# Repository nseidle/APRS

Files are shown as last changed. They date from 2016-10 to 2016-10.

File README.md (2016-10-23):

APRS Entry for 2016 SparkFun AVC
===========================================================

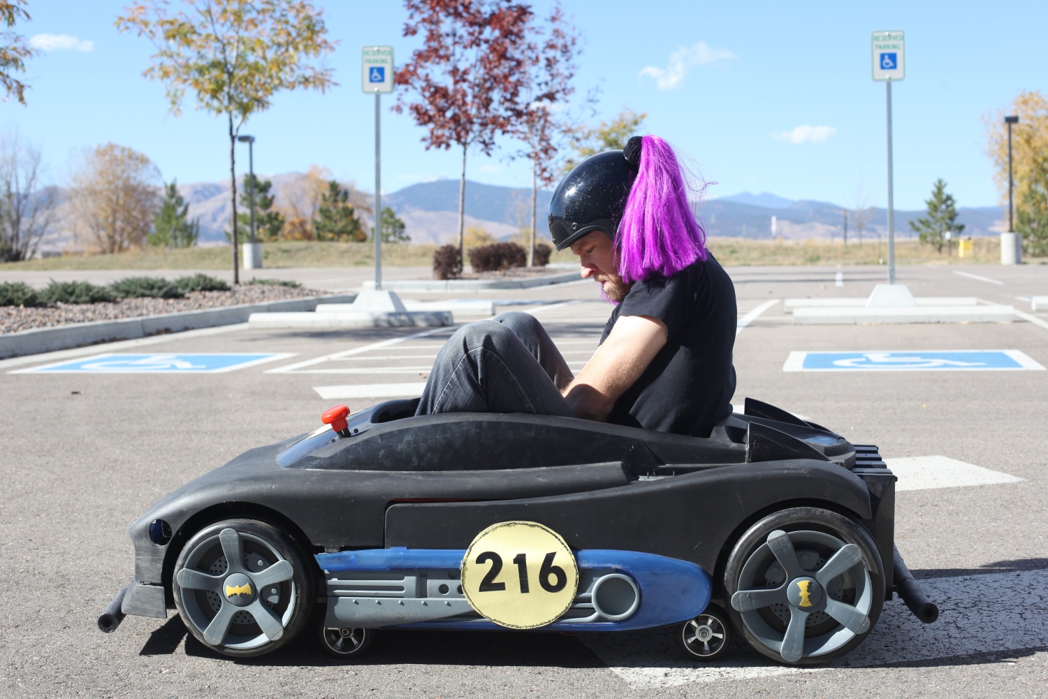
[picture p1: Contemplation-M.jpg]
Nathan in a A+PRS vehicle


This repo contains all the code and PCB layouts used on the A+PRS vehicle Alicia and I entered in the 2016 SparkFun AVC.

Repository Contents
-------------------

The vehicle is broken into sub-systems in order to eat the elephant. Each directory is a sub-system.

Documentation
--------------

There's a tutorial being written.

License Information
-------------------

This is _**open source**_! 

Please use, reuse, and modify these files as you see fit. Please maintain attribution to SparkFun Electronics. Any derivative must be released under the same license.

Distributed as-is; no warranty is given.

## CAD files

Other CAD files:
Old/Models/Chassis.skp

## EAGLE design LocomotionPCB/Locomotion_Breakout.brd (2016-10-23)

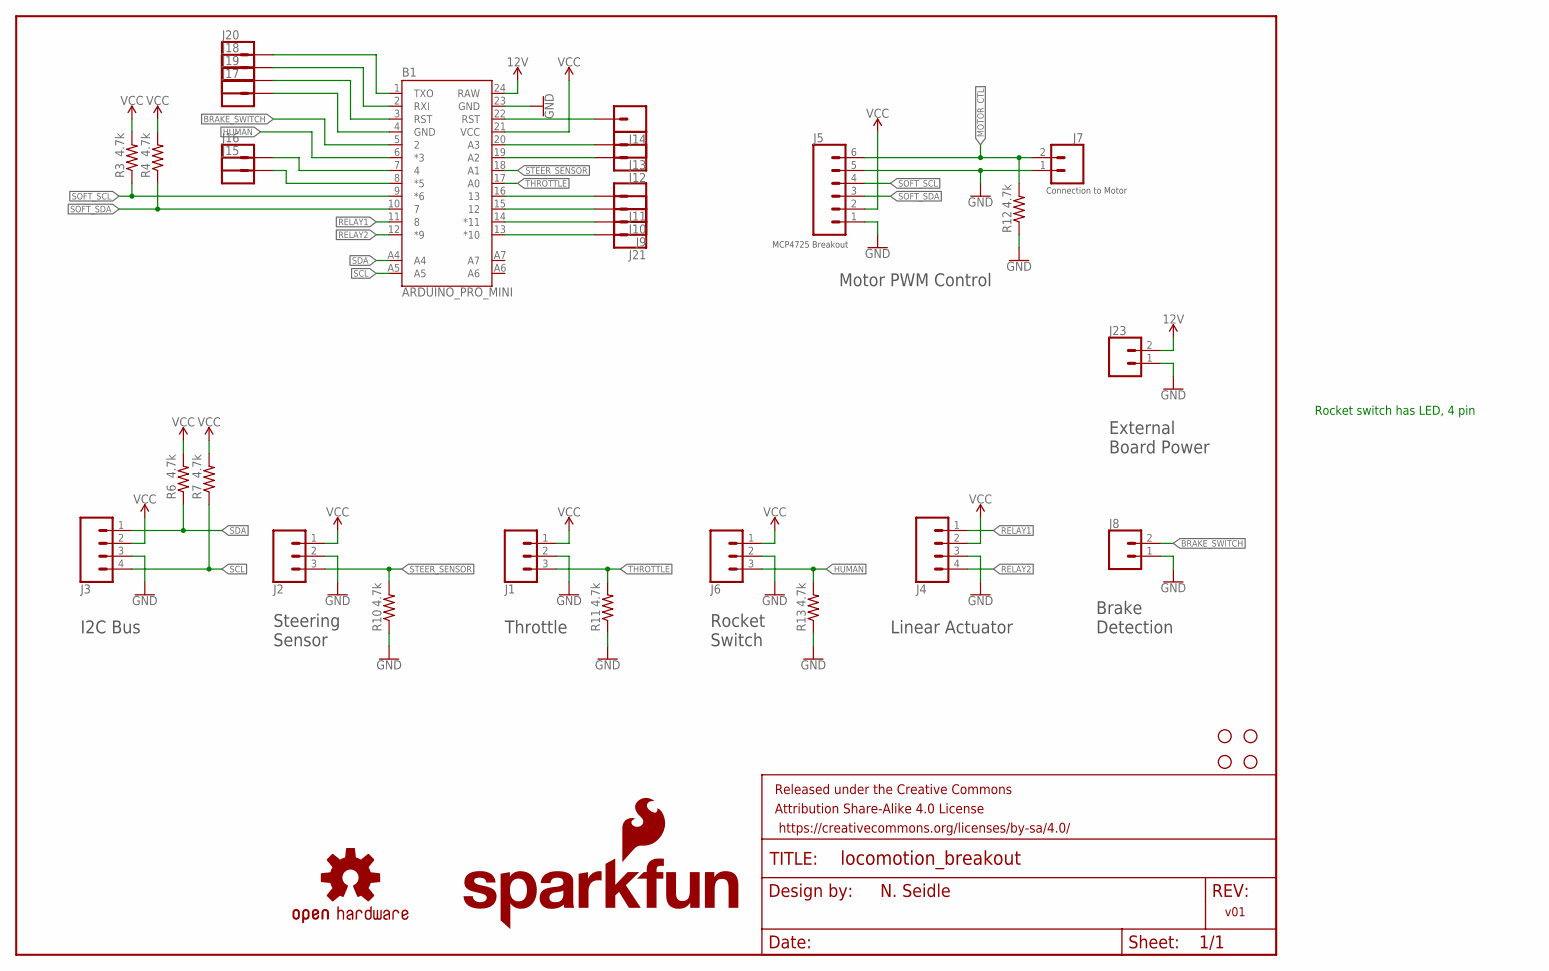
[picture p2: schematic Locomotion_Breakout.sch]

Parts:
B1: ARDUINO_PRO_MINI
FRAME1: FRAME-LETTER; CREATIVE_COMMONS
J1, J2, J6: CONN_03JST-PTH-VERT; JST-3-PTH-VERT
J3, J4: CONN_04JST-PTH-VERT; JST-4-PTH-VERT
J5: CONN_06SILK_FEMALE_PTH; 1X06
J7, J8, J23: CONN_02JST-PTH-VERT; JST-2-PTH-VERT
J9, J10, J11, J12, J13, J14, J15, J16, J17, J18, J19, J20, J21: CONN_01PTH_NO_SILK_YES_STOP; 1X01_NO_SILK
LOGO1: SFE_LOGO_FLAME.1_INCH; SFE_LOGO_FLAME_.1
LOGO2: OSHW-LOGOS; OSHW-LOGO-S
LOGO3: SFE_LOGO_NAME.1_INCH; SFE_LOGO_NAME_.1
R3, R4, R6, R7, R10, R11, R12, R13: 4.7k; AXIAL-0.3
STANDOFF1, STANDOFF2, STANDOFF3, STANDOFF4: STAND-OFF

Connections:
12V: B1.24 (RAW), J23.2
BRAKE_SWITCH: B1.5 (2), J8.2
GND: B1.23 (GND), J1.2, J2.2, J3.3, J4.3, J5.1, J5.5, J6.2, J7.1, J8.1, J23.1, R10.P$1 (1), R11.P$1 (1), R12.P$1 (1), R13.P$1 (1)
HUMAN: B1.6 (*3), J6.3, R13.P$2 (2)
MOTOR_CTL: J5.6, J7.2, R12.P$2 (2)
unnamed: B1.2 (RXI), J18.1
unnamed: B1.3 (RST), J19.1
unnamed: B1.4 (GND), J17.1
unnamed: B1.7 (4), J16.1
unnamed: B1.8 (*5), J15.1
unnamed: B1.13 (*10), J21.1
unnamed: B1.14 (*11), J9.1
unnamed: B1.15 (12), J10.1
unnamed: B1.16 (13), J11.1
unnamed: B1.19 (A2), J12.1
unnamed: B1.20 (A3), J13.1
unnamed: B1.22 (RST), J14.1
unnamed: B1.1 (TXO), J20.1
RELAY1: B1.11 (8), J4.1
RELAY2: B1.12 (*9), J4.4
SCL: B1.A5, J3.4, R7.P$1 (1)
SDA: B1.A4, J3.1, R6.P$1 (1)
SOFT_SCL: B1.9 (*6), J5.4, R3.P$1 (1)
SOFT_SDA: B1.10 (7), J5.3, R4.P$1 (1)
STEER_SENSOR: B1.18 (A1), J2.3, R10.P$2 (2)
THROTTLE: B1.17 (A0), J1.3, R11.P$2 (2)
VCC: B1.21 (VCC), J1.1, J2.1, J3.2, J4.2, J5.2, J6.1, R3.P$2 (2), R4.P$2 (2), R6.P$2 (2), R7.P$2 (2)

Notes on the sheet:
v01
N. Seidle
Throttle
I2C Bus
Linear Actuator
Motor PWM Control
MCP4725 Breakout
Connection to Motor
Steering Sensor
Rocket Switch
Brake Detection
External Board Power
Rocket switch has LED, 4 pin

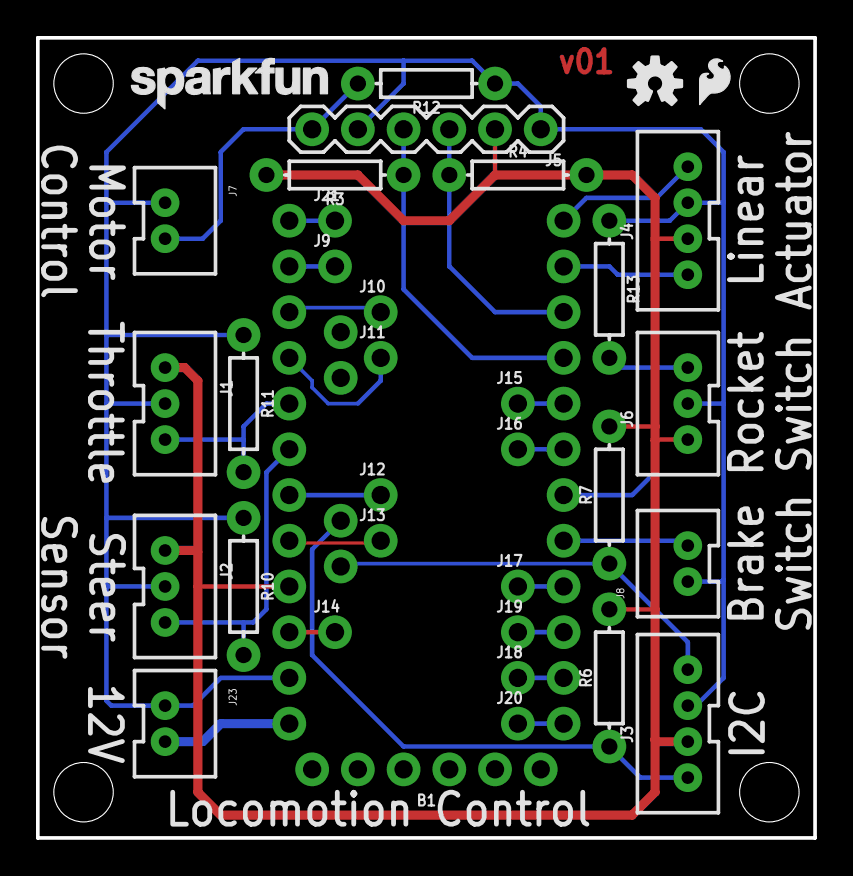
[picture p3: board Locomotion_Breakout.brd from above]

Board: 2 copper layers, 43.2 x 44.5 mm, 39 parts (0 on the bottom side), 27 nets.

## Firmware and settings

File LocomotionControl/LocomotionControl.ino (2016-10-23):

/*
  Locomotion control handles motor and steering over I2C
  Nathan Seidle
  SparkFun Electronics
  3/10/2016

  If at any time the user hits the brakes, the system goes into emergency shut down. The system
  must be power cycled to get out of shut down.

  Master can write two types of data:
    4: requested steering position (to go to) : -99 to 99 (99 = far left, -99 = far right)
        -99 = 100% right, 99 = 100% left, 0 = straight
    6: motor speed: 0 to 99%
  If we don't get a motor speed from master after Xms then we shut down

  Master can read 8 types of data:
    0-3: threshold and calibration settings
    4: requestedSteeringPosition (what steering position are we going to?)
    5: currentSteeringPosition (where is the steering currently?)
    6: motorSpeed (what is the motor currently set to?)
    7: throttlePosition (is the user pressing the throttle?)

  Motor control outputs a PWM analog value (0 to 255 based on incoming 0 to 99%) to the
  30A/1500W DC motor controller. Also reads the throttle (hall effect sensor from 1 to 4V).

  Locomotion controller requires a 5V FTDI. The Kill Switch Pro Mini requires a 3.3V FTDI.

  Steering control outputs to two relays and reads a trim pot on the wheel linkage for feedback.

  If locomotionControl doesn't receive a value every 1000ms the motor will turn off.

  If we use pin 9 and set the PWM freq to 31,250 Hz it is above hearing range.
  Pin 9 with next divisor of 8 makes a really high, annoying pitch.

  I2C Connections:
  SDA: Yellow to Blue on bus
  SCL: Gray to Green on Bus

  For future:
  PCB with connectors
  PCB with weak pull downs on analog pins (throttle, steering position
  pull downs on autonomous switch


*/

#include <SimpleTimer.h> //https://github.com/jfturcot/SimpleTimer
#include <avr/wdt.h> //We need watch dog for this program
#include <EEPROM.h> //Used to remember steer straight values
#include <Wire.h> //Needed for I2C slave communication

#include "pins.h" //Defines how all the hardware is connected

#define AUTO 0
#define HUMAN 2
byte systemMode = HUMAN; //Keeps track of which mode we are in

//Internal EEPROM locations for the straight/min/max values
//These are the min/max angles before we turn off linear actuators
//Thing of them as emergency stops
//Each value is an int, needs two bytes
#define LOCATION_STRAIGHT_ANGLE 0x02
#define LOCATION_MAX_ANGLE 0x04
#define LOCATION_MIN_ANGLE 0x06
#define LOCATION_POT_DELTA 0x08 //The + or - amount of pot reading before we believe we are at the requested steering angle

byte whichSetting = 0; //This is the pseudo 'memory address' that the master will set to read/write I2C stuff
//The following variables are 0, 1, 2, etc
int settingAngleStraight;
int settingAngleMax;
int settingAngleMin;
int settingPotDelta;
int requestedSteeringPosition;
int currentSteeringPosition;
int motorSpeed; //What the motor is at right now?
int throttlePosition; //Is the user pressing the throttle?
int brakeOn;

int masterMotorValue = 0;

SimpleTimer timer;
long secondTimerID;
long motorUpdateID;
long timeOutID;
long steeringID;
long throttleID;
long brakeCheckID;
long serialUpdateID;

#define MAX_TIMEOUT 3000L //Number of ms between motor speed updates before system goes into safe mode
#define MOTORUPDATE_TIME 100L //Time between updating the motor
#define STEERING_CHECK_TIME 100 //Number of ms between checking the steering position
#define THROTTLE_CHECK_TIME 25L //Number of ms between checking the user's throttle
#define BRAKE_CHECK_TIME 25L //Number of ms between checking the user's brake
#define SERIAL_CHECK_TIME 500L //Print current state of things and look for incoming serial
#define SECOND_CHECK_TIME 1000L //Blink the LED to show life

//0x0D is locomotion controller
//0x0E is Sensor Collator
//0x0F is Laser Collator
//0x1E is HMC5883L magneto
//0x72 is the OpenLCD

#define LOCOMOTION_ADDRESS 0x0D
#define SENSOR_COLLATOR_ADDRESS 0x0E
#define LASER_COLLATOR_ADDRESS 0x0F
#define DISPLAY_ADDRESS1 0x72 //This is the default address of the OpenLCD
#define EXTERNAL_EEPROM 0x50 //Used for storing waypoints and settings

//Define the various system states
char motorState;
#define MOTOR_STOP 'S'
#define RECEIVED_SETTING 'R'
#define RECEIVED_THROTTLE 'T'
#define MOTOR_USER_EMERGENCY_STOP 'U'
char steerState;
#define STEER_STOP 's'
#define STEER_ARRIVED 'a'
#define STEER_LEFT 'l'
#define STEER_RIGHT 'r'
#define STEER_TOO_LEFT 'k'
#define STEER_TOO_RIGHT 'j'
#define STEER_USER_EMERGENCY_STOP 'u'

//Define the min/max thresholds of the hall effect sensor
//Analog value is 172 to 858
#define HALL_MIN 19 //Actual is 16 or 17
#define HALL_MAX 84
#define HALL_DELTA 2

//For my particular relay setup driving the pin high causes the relay to turn off
#define STEER_RELAY_OFF HIGH
#define STEER_RELAY_ON LOW

#define ERROR_THROTTLE_RANGE 2
#define ERROR_THROTTLE_MISSING 3

unsigned long timeSinceLastUpdate = 0; //Amount of time since last command from master
unsigned long throttleOffline = 0; //Amount of time since we last detected the throttle online

void setup()
{
  wdt_reset(); //Pet the dog
  wdt_disable(); //We don't want the watchdog during init

  //Turn off motor above all
  setThrottle(0);

  Serial.begin(115200);

  pinMode(STAT, OUTPUT);

  setupSteering(); //Set the GPIOs
  setupMotor(); //Set the motor and throttle pins up
  setupBrake(); //Set up the brake switch
  setupModeSwitch(); //Setup weird GPIOs to check the auto switch

  Wire.begin(LOCOMOTION_ADDRESS); //Join I2C bus as slave at this address
  Wire.onRequest(requestEvent); //When master is asking for something, call this function
  Wire.onReceive(receiveEvent); //When we get I2C bytes, call this function

  serialUpdateID = timer.setInterval(SERIAL_CHECK_TIME, printUpdate); //Print a system update every Xms
  secondTimerID = timer.setInterval(SECOND_CHECK_TIME, secondPassed); //Call secondPassed every Xms
  timer.setInterval(1000L, checkAutoModeSwitch); //Check the switch every second to see what mode we're in

  //Test
  //This was added when the steeringUpdate function failed to be called normally
  steeringID = timer.setInterval(STEERING_CHECK_TIME, steeringUpdate);

  //Used to overwrite/reset bad settings when we take on/off the trimpot
  /*settingAngleStraight = 420;
  writeEEPROMInt(LOCATION_STRAIGHT_ANGLE, settingAngleStraight); //Record to EEPROM

  settingAngleMax = 550; //To the right
  writeEEPROMInt(LOCATION_MAX_ANGLE, settingAngleMax); //Record to EEPROM

  settingAngleMin = 290; //To the left
  writeEEPROMInt(LOCATION_MIN_ANGLE, settingAngleMin); //Record to EEPROM*/

  Serial.println("Motor and Steering Controller Online");

  wdt_reset(); //Pet the dog
  wdt_enable(WDTO_1S); //Unleash the beast
}

void loop()
{
  wdt_reset(); //Pet the dog
  timer.run(); //Update any timers we are running
}

//Blink the status LED to show we are alive
void secondPassed()
{
  digitalWrite(STAT, !digitalRead(STAT));
}

//Every Xms print a system update and look for input from user
void printUpdate()
{
  if (motorState == MOTOR_USER_EMERGENCY_STOP)
  {
    Serial.println("Emergency Stop");
  }
  else
  {
    Serial.print(" motorValue[");
    Serial.print(masterMotorValue);
    Serial.print("]");

    Serial.print(" Mode[");
    if (systemMode == HUMAN) Serial.print("HUMAN");
    if (systemMode == AUTO) Serial.print("AUTO");
    Serial.print("]");

    Serial.print(" brake[");
    if (brakeOn == true) Serial.print("ON");
    else Serial.print("OFF");
    Serial.print("]");

    Serial.print(" speed[");
    Serial.print(motorSpeed, DEC);
    Serial.print("]");
    //Serial.print(" motorState: ");
    //Serial.print(motorState);
    //Serial.print(" ThrottleIn: ");
    //Serial.print(throttlePosition, DEC);

    Serial.print(" potDelta[");
    Serial.print(settingPotDelta);
    Serial.print("]");

    Serial.print(" currentSteer[");
    Serial.print(currentSteeringPosition);
    Serial.print("]");

    Serial.print(" requestSteer[");
    Serial.print(requestedSteeringPosition);
    Serial.print("]");

    Serial.print(" Steer[");
    if (steerState == STEER_STOP) Serial.print("STOP");
    if (steerState == STEER_ARRIVED) Serial.print("Arrived");
    if (steerState == STEER_RIGHT) Serial.print("RIGHT");
    if (steerState == STEER_LEFT) Serial.print("LEFT");
    if (steerState == STEER_TOO_RIGHT) Serial.print("MAX R");
    if (steerState == STEER_TOO_LEFT) Serial.print("MAX L");
    Serial.print("]");

    Serial.println();
  }

  if (Serial.available())
  {
    char incoming = Serial.read();
    Serial.print("!");

    if (incoming == 'S' || incoming == '0') //Stop!
    {
      timeSinceLastUpdate = millis();
      if (motorState != MOTOR_USER_EMERGENCY_STOP) motorState = MOTOR_STOP;
      motorSpeed = 0;

      steerStop(); //Stop any steering actuation
      steerState = STEER_USER_EMERGENCY_STOP;
    }
    else if (incoming == 'a') //Turn up motor some
    {
      timeSinceLastUpdate = millis();
      if (motorState != MOTOR_USER_EMERGENCY_STOP) motorState = RECEIVED_SETTING;
      motorSpeed += 5;
      if (motorSpeed > 99) motorSpeed = 99;
    }
    else if (incoming == 'z') //Turn down motor
    {
      timeSinceLastUpdate = millis();
      if (motorState != MOTOR_USER_EMERGENCY_STOP) motorState = RECEIVED_SETTING;
      motorSpeed -= 5;
      if (motorSpeed < 0) motorSpeed = 0;
    }
    else if (incoming == 'c') //Set the center point
    {
      calibrateCenter();
    }
    else if (incoming == '[')
    {
      //Steer left a little bit
      requestedSteeringPosition += 5;
    }
    else if (incoming == ']')
    {
      //Steer right a little bit
      requestedSteeringPosition -= 5;
    }
  }
}

//The switch is wired oddly so we have to set a bunch of pins up for pull downs and things
void setupModeSwitch()
{
#define LED_OFF HIGH
#define LED_ON LOW

  pinMode(MODE_SWITCH_LED, OUTPUT);
  digitalWrite(MODE_SWITCH_LED, LED_OFF); //Turn off LED

  pinMode(MODE_SWITCH, INPUT);
}

//Checks to see if the Mode Switch is turned on
//Sets the global mode variable
void checkAutoModeSwitch()
{
#define LED_OFF HIGH
#define LED_ON LOW

#define MANUAL_MODE LOW
#define AUTO_MODE HIGH

  if (digitalRead(MODE_SWITCH) == MANUAL_MODE) //Switch is open, we are in manual mode
  {
    throttleID = timer.setInterval(THROTTLE_CHECK_TIME, throttleUpdate); //Read the throttle position only if human is driving

    digitalWrite(MODE_SWITCH_LED, LED_OFF);
    systemMode = HUMAN;
  }
  else
  {
    timer.disable(throttleID); //Stop the throttle from being checked

    digitalWrite(MODE_SWITCH_LED, LED_ON);
    systemMode = AUTO;
  }
}

void blinkError(int errorType)
{
  wdt_reset(); //Pet the dog
  wdt_disable(); //We don't want the watchdog anymore

  motorSpeed = 0;
  setThrottle(motorSpeed); //Shut it down

  Serial.println("Blinking Error. Shutting down.");

  //Disable all timers
  timer.disable(timeOutID);
  timer.disable(secondTimerID);
  timer.disable(motorUpdateID);
  timer.disable(steeringID);
  timer.disable(throttleID);
  timer.disable(brakeCheckID);
  timer.disable(serialUpdateID);

  while (1)
  {
    delay(3000);

    for (int x = 0 ; x < errorType ; x++)
    {
      digitalWrite(STAT, HIGH);
      delay(250);
      digitalWrite(STAT, LOW);
      delay(250);
    }
  }
}

//Takes an average of readings on a given pin
//Returns the average
int averageAnalogRead(byte pinToRead)
{
  byte numberOfReadings = 16;
  unsigned int runningValue = 0;

  for (int x = 0 ; x < numberOfReadings ; x++)
  {
    runningValue += analogRead(pinToRead);
    delayMicroseconds(10);
  }
  runningValue /= numberOfReadings;

  return (runningValue);
}

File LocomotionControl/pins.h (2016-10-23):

//Hardware definitions
//-=-=-=-=-=-=-=-=-=-=-=-=-=-=-=-=-=-=-=-=-=-=-=-=-=-=-=-=-=-=-=-=-=-=-=-=-=-=-=-=-=-=
#define THROTTLE_IN A0

//#define THROTTLE_OUT 9 //PWM base frequency is 31250 Hz, above hearing range

#define STEER_POT A1

//The rocket switch is wired super weird. The pin on side is LED common. And LED gets power from either
//of the lower lugs (+). Lug on left is wired 5V, lug on right is wired switch with a pull-down.
//So when rocket is thrown, 5V goes to switch and also to LED. When LED goes low, LED turns on.
#define MODE_SWITCH_LED 4 //Yellow
#define MODE_SWITCH 3 //Black

#define RELAY1 8
#define RELAY2 9

#define BRAKE_SWITCH 2

#define STAT 13
//-=-=-=-=-=-=-=-=-=-=-=-=-=-=-=-=-=-=-=-=-=-=-=-=-=-=-=-=-=-=-=-=-=-=-=-=-=-=-=-=-=-=

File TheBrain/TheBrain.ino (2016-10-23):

/*
  The Brain - Master Controller for AVC/PRS Vehicle
  Nathan Seidle
  SparkFun Electronics
  3/27/2016

  Master controller sends bytes to the steering controller and read values from
  locomotion controller, sensor collator, and laser collator

  From all the sensor information we make the navigation decisions

  I2C Connections:
  SDA: Blue on bus
  SCL: Green on Bus
*/

#include <SimpleTimer.h> //https://github.com/jfturcot/SimpleTimer
#include <Wire.h> //Needed for I2C slave communication

#include "pins.h"

#include "doubleEEPROM.h" //Needed for Waypoint recording on external EEPROM

#include "wd.h" //Comes from https://github.com/adafruit/Adafruit_SleepyDog/blob/master/utility/WatchdogSAMD.cpp

WatchdogSAMD dog;

#define COMPASS_LOCATION 1 //Compass offset is two bytes
#define UNDERWAY_LOCATION 8 //Location in EEPROM for underway variable. Helps us recover from WDT reset

#define UNDERWAY_STOPPED 255

SimpleTimer timer;
long secondTimerID;
long navigateTimerID; //Keeps track of when we should update heading and turning

//Global variables
//-=-=-=-=-=-=-=-=-=-=-=-=-=-=-=-=-=-=-=-=-=-=-=-=
boolean statLEDon = false; //Keep track of the state of the status LED because there is MOSFET controlling it

struct SOTW //State of the World
{
  double gpsLat;
  double gpsLong;
  float gpsAge;
  float gpsHDOP;
  int gpsSIV;
  int heading;

  byte Underway;

  int settingAngleStraight;
  int settingAngleMax;
  int settingAngleMin;
  int settingPotDelta;
  int requestedSteeringPosition;
  int currentSteeringPosition;
  int motorSpeed;
  int throttlePosition;
  int systemMode;
  int brakeOn;

  long leftDistance;
  long rightDistance;
  long centerDistance;
  long leftAge;
  long rightAge;
  long centerAge;
};

SOTW batmobile;

struct Coordinates
{
  double gpsLong;
  double gpsLat;
};

#define NUMBER_OF_WAYPOINTS 10 //Increase this if we want more waypoints
struct Coordinates wayPoint[NUMBER_OF_WAYPOINTS]; //These are our stored contest waypoints
int currentWP = 0; //This is our waypoint token. Start at zero.

String msg; //Generic string used for debug printing on LCD and serialUSB

boolean printedFirstTime = false; //This is just used to print the opening menu once
//-=-=-=-=-=-=-=-=-=-=-=-=-=-=-=-=-=-=-=-=-=-=-=-=

//Settings
//-=-=-=-=-=-=-=-=-=-=-=-=-=-=-=-=-=-=-=-=-=-=-=-=
int cruisingSpeedForAuto = 15; //15%? Maybe?

unsigned int left_wall_min_distance = 750; //750mm to wall before we start to steer away
unsigned int right_wall_min_distance = 750; //750mm to wall before we start to steer away

//We want a 2.5m halo. If we are within 8.2 of the spot, we're close enough.
double halo_long_delta = 8.2 / 101 / (double)60; //1" = 101ft, 2.5m = 8.2ft
//8.2/101 / 60 = 0.0013531353135
double halo_lat_delta = 0.1 / (double)60; //1" = ~80ft, 2.5m = 8.2ft = 0.1"
//0.1/60 = 0.0016666666

//These were found by adjusting wheels and taking readings
unsigned int a_little_right = 561;
unsigned int a_lot_right = 551;
unsigned int a_little_left = 565;
unsigned int a_lot_left = 575;

long left_wall_time_before_a_lot_turn = 1000; //Amount of time (turning a little) before we give up and turn a lot
long right_wall_time_before_a_lot_turn = 1000;

long wall_left_timestamp; //Record when we saw a wall so that we can go hard away if needed
long wall_right_timestamp;

//We're not sure how the compass will be stuck to car. Use cell phone to figure out offset from N.
int compassOffset; //61, Add a number that is the difference between cell phone N and what nav says is N
int rawHeading;
//-=-=-=-=-=-=-=-=-=-=-=-=-=-=-=-=-=-=-=-=-=-=-=-=

//0x0D is locomotion controller
//0x0E is Sensor Collator
//0x0F is Laser Collator
//0x1E is HMC5883L magneto
//0x72 is the OpenLCD

#define LOCOMOTION_ADDRESS 0x0D
#define SENSOR_COLLATOR_ADDRESS 0x0E
#define LASER_COLLATOR_ADDRESS 0x0F
#define DISPLAY_ADDRESS1 0x72 //This is the default address of the OpenLCD
#define EEPROM_ADDRESS 0x50 //Used for storing waypoints and settings

#define LOCO_REQUESTED_STEERING 4
#define LOCO_CURRENT_STEERING 5
#define LOCO_MOTOR_SPEED 6
#define LOCO_THROTTLE_POSITION 7
#define LOCO_SYSTEM_MODE 8
#define LOCO_BRAKE_ON 9
#define AUTO 0
#define HUMAN 2

#define SENSE_HEADING 0
#define SENSE_LAT 1
#define SENSE_LONG 2
#define SENSE_ALT 3
#define SENSE_HDOP 4
#define SENSE_SIV 5
#define SENSE_AGE 6

#define DISTANCE_ALL 0
#define DISTANCE_LEFT 1
#define DISTANCE_CENTER 2
#define DISTANCE_RIGHT 3
#define DISTANCE_LEFT_AGE 4
#define DISTANCE_CENTER_AGE 5
#define DISTANCE_RIGHT_AGE 6

void setup()
{
  dog.reset(); //pet the dog
  dog.disable();

  pinMode(STAT, OUTPUT);
  secondTimerID = timer.setInterval(1000L, secondPassed); //Call secondPassed every Xms

  SerialUSB.begin(115200);
  //We will get stuck here if USB cable is not attached.
  //Uncomment for debug/testing
  //while (!SerialUSB); //Magic code that waits for serial port to be allowed to print

  //dog.enable(512); //Hope to hit 512ms
  //dog.enable(5120); //Hope to hit 512ms
  dog.reset(); //pet the dog

  Wire.begin(); //Join I2C bus as master

  setupButton(); //Setup things to read the user button

  resetLCD();
  clearLCD();
  blastMessage("Hello");
  delay(250);
  dog.reset(); //pet the dog
  clearLCD();

  pingControllers(); //See who responds
}

void loop()
{
  dog.reset(); //pet the dog
  timer.run(); //Update any timers we are running

  if (SerialUSB.available() || printedFirstTime == false)
  {
    printedFirstTime = true; //Don't print opening menu a second time

    char incoming = SerialUSB.read();

    SerialUSB.println("t: Test menu");
    SerialUSB.println("p: Enter waypoints");
    SerialUSB.println("n: Navigate");
    SerialUSB.println("c: Compass");
    SerialUSB.println();

    if (incoming == 't')
      testMenu();
    else if (incoming == 'p')
      enterWayPoints();
    else if (incoming == 'n')
    {
      SerialUSB.println("Are you sure? y/n:");
      while (!SerialUSB.available()) dogDelay(1);
      if (SerialUSB.read() == 'y') navigate();

      //If we exit from navigate, return to stopped condition
      batmobile.Underway = UNDERWAY_STOPPED;
      writeUnderway();
    }
    else if(incoming == 'c')
    {
      compassCalibrate();
    }
  }

  //See if user is holding button
  if (digitalRead(DUIT_BUTTON) == LOW) buttonPressed();
}
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

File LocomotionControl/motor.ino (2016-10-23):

#include <SoftwareWire.h> //Needed for software I2C to MCP4725
SoftwareWire softWire(7, 6, false); //SDA, SCL, don't use internal pullups
#define MCP4725_ADDR 0x60   


void setupMotor()
{
  pinMode(THROTTLE_IN, INPUT);

  softWire.begin(); //Setup the software based I2C for analog motor control

  timeOutID = timer.setInterval(MAX_TIMEOUT, motorSafetyCheckIn); //If after Xms we have no update then shut off motor
  motorUpdateID = timer.setInterval(MOTORUPDATE_TIME, motorUpdate); //Update motor every Xms
  
  motorSpeed = 0;
  motorState = MOTOR_STOP;
}
//Every few ms read the hall effect sensor on the user throttle
void throttleUpdate()
{
  int reading = averageAnalogRead(THROTTLE_IN);

  Serial.print("analog reading: ");
  Serial.println(reading);

  //This is a safety check. Shouldn't be allowed to happen but I've seen it happen when
  //the throttle becomes disconnected  
  if(reading < 10) //Pull down brings this to 0
  {
    if(millis() - throttleOffline > 1000)
    {
      //Throttle hasn't been disconnected for 2s, oh shit
      motorState = MOTOR_STOP;
      motorSpeed = 0;
      setThrottle(motorSpeed); //Shut it down
  
      Serial.println("Throttle disconnect detected. Powering down.");
      blinkError(ERROR_THROTTLE_RANGE);
    }
  }
  else
  {
    //Throttle was detected so update its time stamp
    throttleOffline = millis();
  }

  throttlePosition = map(reading, 0, 1023, 0, 99); //Map the throttle reading to the expected 0 to 99 % control value

  //We need to map the hall effect sensor that goes from 1-4V to 0 to 99
  throttlePosition = map(throttlePosition, HALL_MIN, HALL_MAX, 0, 99);

  throttlePosition = constrain(throttlePosition, 0, 99); //Make sure we don't go above 99 or below 0
}

//Check to see if we have received an update
//If we haven't heard from the main controller within a certain amount of time then shut down
void motorSafetyCheckIn()
{
  wdt_reset(); //Pet the dog

  if (motorState != MOTOR_STOP && (millis() - timeSinceLastUpdate) > MAX_TIMEOUT)
  {
    if(motorState != MOTOR_USER_EMERGENCY_STOP) motorState = MOTOR_STOP;
    motorSpeed = 0;
    setThrottle(motorSpeed); //Shut it down

    Serial.println("No update. Shutting down.");
  }
}

//Every few 100 ms update the motor spped
void motorUpdate()
{
  //Here is where we decide whether to listen to the human or not
  //If we have input over I2C we take it
  //If not, we take the throttle value
  //If not throttle value then go to zero

  if (systemMode == AUTO && motorSpeed > 0 ) //motorSpeed comes over I2C
  {
    masterMotorValue = motorSpeed;
  }
  else if (systemMode == HUMAN && throttlePosition > 0)
  {
    //throttlePosition comes from reading the user's input or throttle position
    //It only comes into play if the Manual Override Switch is activated
    //And we only get this far if the system is *not* receiving an I2C command (motorSpeed)
    masterMotorValue = throttlePosition; 
  }
  else
    masterMotorValue = 0; //If nothing else, just stop

  masterMotorValue = constrain(masterMotorValue, 0, 99); //Make sure we don't go above 99
  byte pwmValue = map(masterMotorValue, 0, 99, 0, 255);

  setThrottle(pwmValue);
}

//Controls the MCP4725 over software I2C to set the analog value sent to the motor controller
//Input is a PWM value of 0 to 255
//Output is 0 to 5V
void setThrottle(byte throttleValue)
{
  uint16_t mcpValue = map(throttleValue, 0, 255, 0, 4095);

  softWire.beginTransmission(MCP4725_ADDR);
  softWire.write(64); //Command to update the DAC
  softWire.write(mcpValue >> 4); // the 8 most significant bits...
  softWire.write(mcpValue << 4); // the 4 least significant bits...
  softWire.endTransmission();
}

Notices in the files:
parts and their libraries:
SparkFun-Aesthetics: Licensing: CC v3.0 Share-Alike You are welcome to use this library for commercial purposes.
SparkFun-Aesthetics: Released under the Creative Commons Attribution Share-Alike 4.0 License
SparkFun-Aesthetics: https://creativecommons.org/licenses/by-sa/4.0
